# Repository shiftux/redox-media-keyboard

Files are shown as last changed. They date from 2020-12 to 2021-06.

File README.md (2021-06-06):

# Redox Media Keyboard

I've made a custom adaptation of the [Redox](https://hackaday.io/project/160610-redox-keyboard) keyboard, accommodating media buttons as well as a volume knob and a scroll wheel.

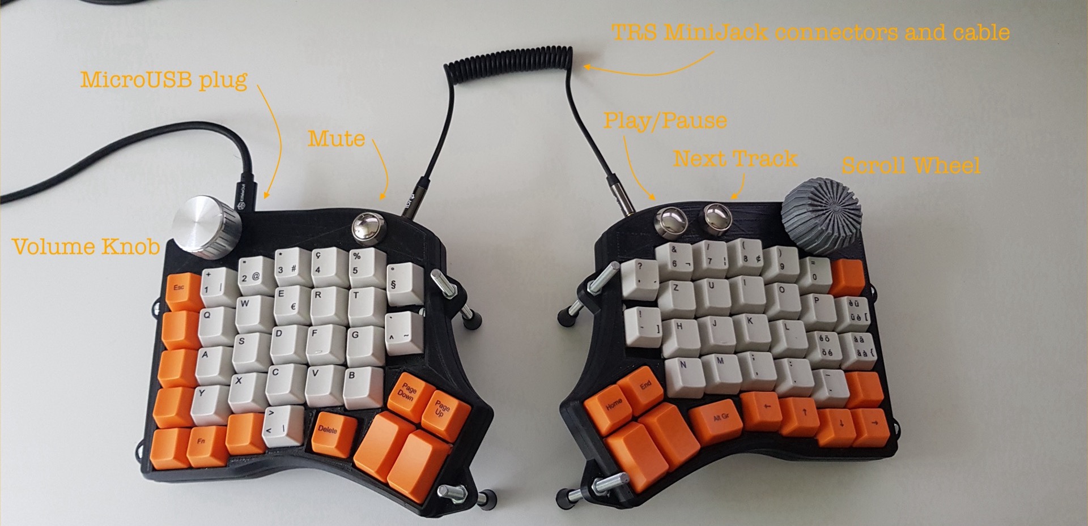
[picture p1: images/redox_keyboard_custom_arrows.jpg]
The Redox Media Keyboard


## Detailed report and video
I've written a [detailed article](https://shiftux.org/making_projects/keyboard.html) and created a [video](https://youtu.be/Cwkf7HFcUkY) video explaining the pros and cons of such a keyboard as well as a build and programming guide.

I recommend reading at least the part about testing of switches and deciding what keyboard you want to go for in the above [article](https://shiftux.org/making_projects/keyboard.html), it will save you from a lot of work later on...

## Wiring diagram
Keyboards are typically wired in a matrix, where every switch is connected to 1 row and 1 column. If the microcontroller detects a connection between a row and a column, it identifies which key is pressed. The [video](https://youtu.be/Cwkf7HFcUkY) explains the wiring in more detail with useful hints of how to prepare the wires.

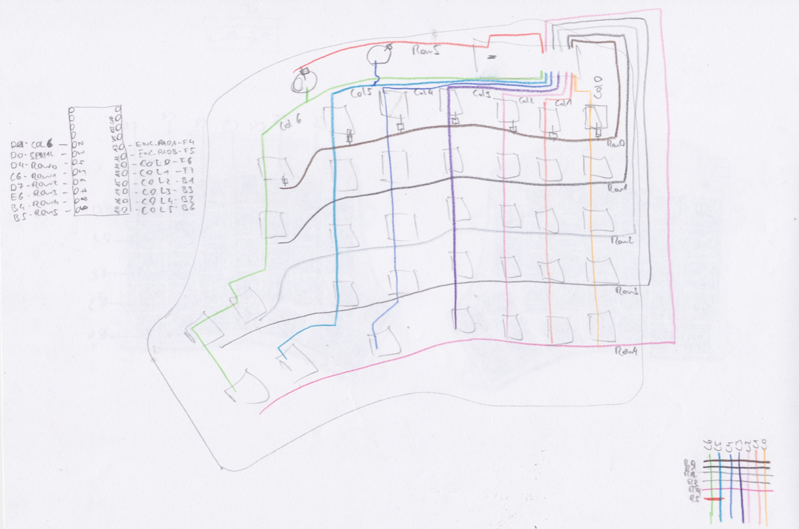
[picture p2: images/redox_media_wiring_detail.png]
The Redox Media Keyboard

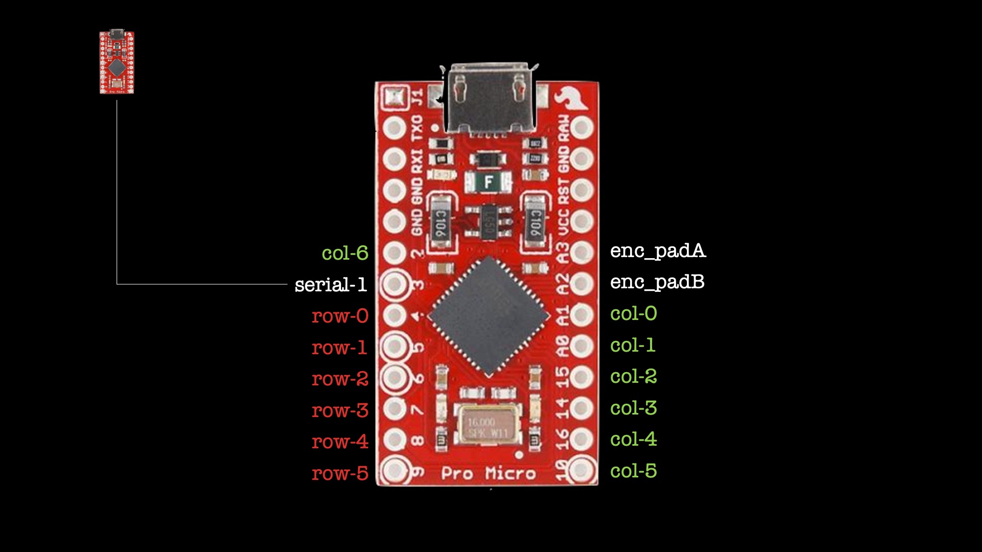
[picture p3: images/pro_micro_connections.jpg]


The wiring diagrams from the Redox community can be found [here](https://hackaday.io/project/160610/logs?sort=oldest)

For easier wiring I recommend first soldering the diodes and then preparing partially de-insulated cables, details can be learned in the [video](https://youtu.be/Cwkf7HFcUkY)  or in [this guide](https://geekhack.org/index.php?topic=87689.0).

## Programming
The keyboard software is based on the QMK framework, as is the original Redox. I've submitted a PR to QMK adding a media layout and corresponding key map. Also instructions to apply and flash the firmware are layed out there, refer to the [Redox Media section in the QMK repo](https://github.com/qmk/qmk_firmware/pull/13084) (currently a PR, but you can check the changes or [my fork](https://github.com/shiftux/qmk_firmware/tree/redox_media/keyboards/redox/media) of the QMK repo in the meantime).

While generating a new layout I highly recommend using the amazing [QMK key tester](https://config.qmk.fm/#/test).

## Bill of material
- [key tester](https://www.amazon.fr/AKWOX-M%C3%A9canique-Interrupteurs-Dampeners-Extracteur/dp/B01GZHU1EG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)
- [sample switches](https://www.pcgamingrace.com/products/glorious-mx-switch-sample-pack)
- [switches (Kailh Pro Purple)](https://www.digitec.ch/de/s1/product/glorious-pc-gaming-race-kailh-pro-purple-switches-120-stueck-maus-tastatur-zubehoer-12826227)
- [Sparkfun pro micro 5V](https://www.play-zone.ch/de/sparkfun-arduino-pro-micro-5v-16mhz.html) 2x
- [curled 3.5mm cable](https://www.brack.ch/hama-audio-kabel-klinke-3-182926)
- [rotary encoder](https://www.digitec.ch/de/s1/product/velleman-digital-rotary-encoder-modul-entwicklungsboard-kit-12256627) 2x
- [shape cable](https://www.fust.ch/de/p/pc-tablet-handy/pc-komponenten/kabel-adapter/delock/usb-otg-kabel-microb-shapecable-0-15-m-8289927.html)
- [1N4148-200mA diodes (as many as you intend to use switches)](https://www.amazon.fr/dp/B07CTW5L3W/ref=pe_3044141_185740131_TE_item)
- [media buttons](https://www.aliexpress.com/item/32908474287.html) 3x
- [micro USB cable](https://www.amazon.fr/dp/B07Q5NQFL1/ref=pe_3044141_185740131_TE_item)
- volume knob
- scroll wheel (printed)
- 5mm threaded rod with nuts
- hook up wire (ideally multiple colors)
- key caps. You can use any old MX type key caps from an old keyboard or order a set of custom ones. I got mine from [here](https://www.maxkeyboard.com/iso-layout-custom-color-cherry-mx-keycap-set-top-print-blank.html), another alternative would be [this](https://candykeys.com/).

## CAD files
The original Redox CAD files (SCAD) are open source and available [here](https://github.com/Lenbok/scad-keyboard-cases). I've modified those adding some extra space at the top to accommodate the media buttons and two knobs. Also, I changed the bottom part of the keyboard so that it has a custom micro-USB slot which perfectly fits the shape cable holding it in place and exposing one end as port socket for the computer-to-keyboard USB cable, that's where the [shape cable](https://www.fust.ch/de/p/pc-tablet-handy/pc-komponenten/kabel-adapter/delock/usb-otg-kabel-microb-shapecable-0-15-m-8289927.html) comes in.

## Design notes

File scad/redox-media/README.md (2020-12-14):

## Redox Keyboard with media buttons and scroll wheel

I wanted to design a new case for the Redox that was inspired both
by the Redox Rev1 case and the Iris, and I thought it would be nice to
start with the layout from the [Keyboard Layout
Editor](http://www.keyboard-layout-editor.com/) JSON file (in this way
it could be extended to other keyboards). Existing tools I had found for
going from KLE JSON to OpenSCAD didn't work for split keyboards where
some keys are rotated, so an updated tool is provided here that seems to
work on the split keyboards I have tried.

redox-top

redox-exploded

redox-completed

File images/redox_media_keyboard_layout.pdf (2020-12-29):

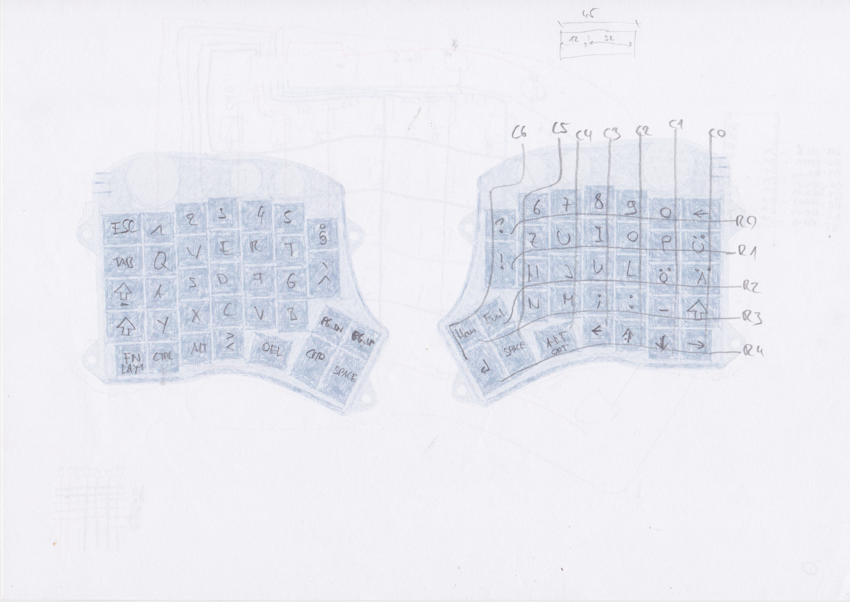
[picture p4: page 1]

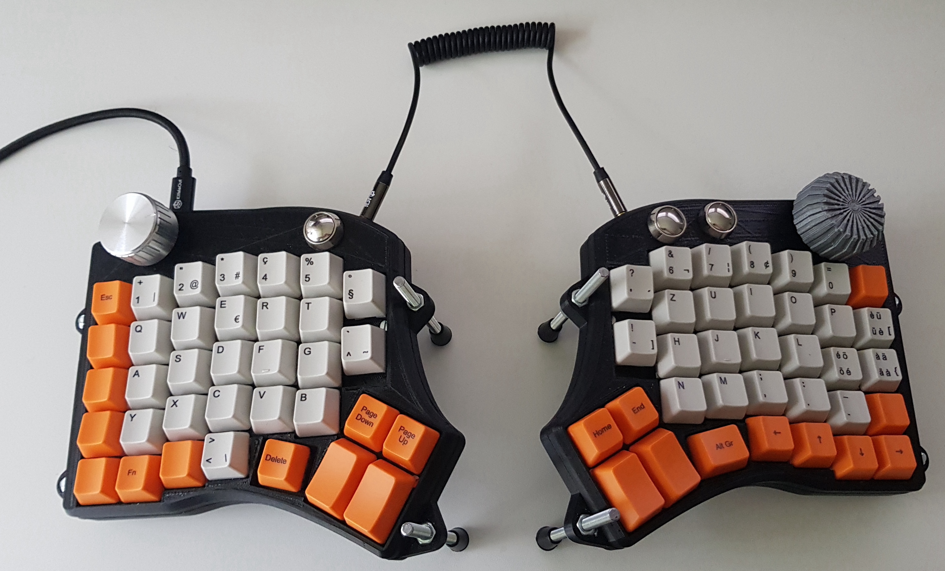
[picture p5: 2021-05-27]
images/the_keyboard.jpg

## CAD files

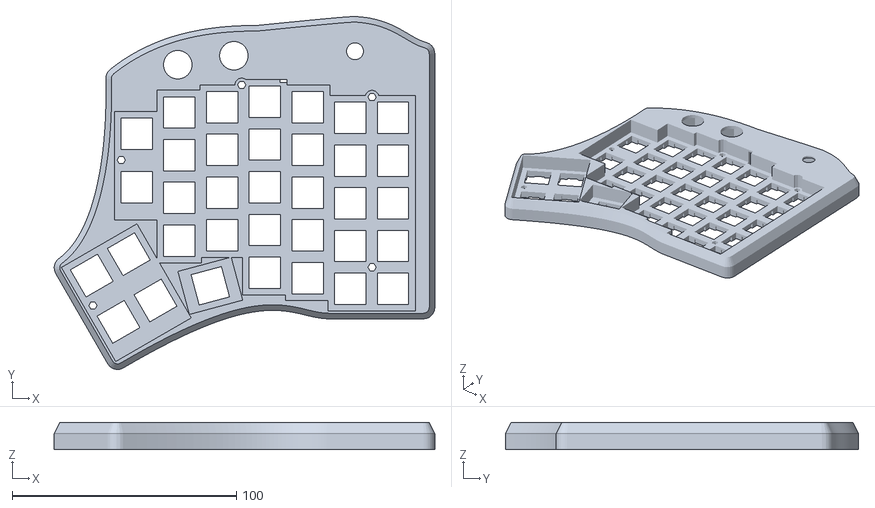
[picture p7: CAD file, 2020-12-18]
CAD/redox-case_top_right.stl
169.7 x 157.4 x 12.2

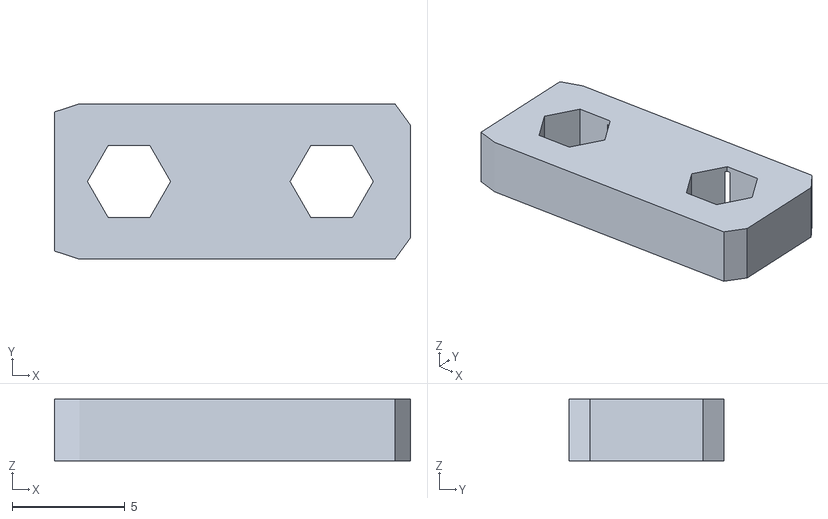
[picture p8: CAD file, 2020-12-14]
scad/misc/stls/Micro_USB_Spacer.stl
15.8 x 6.90 x 2.75

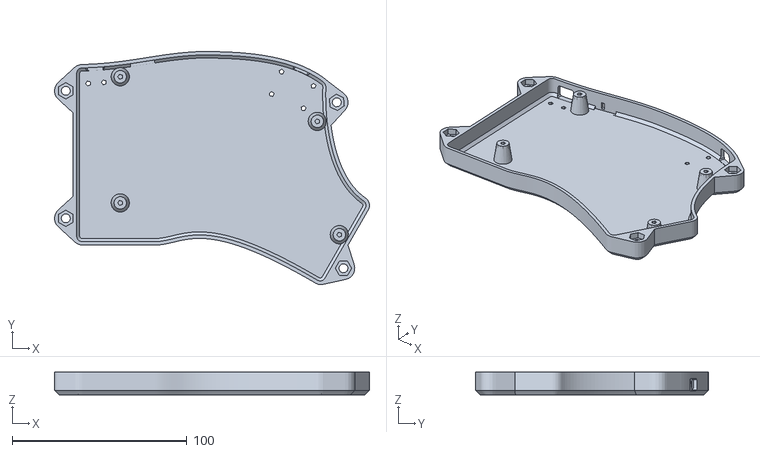
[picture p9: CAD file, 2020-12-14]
scad/redox-media/stls/redox-rev0b-bottom.stl
180.3 x 133.4 x 13.0

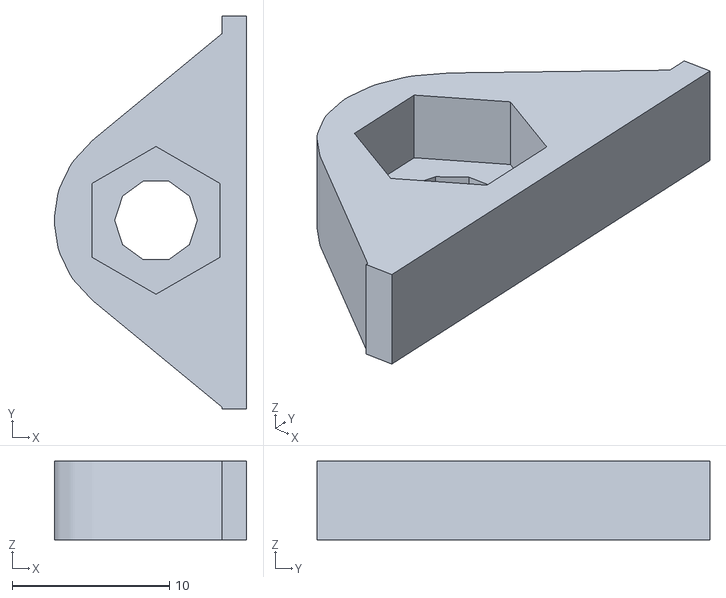
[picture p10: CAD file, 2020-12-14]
scad/stl/redox-case_test.stl
12.2 x 25.0 x 5.00

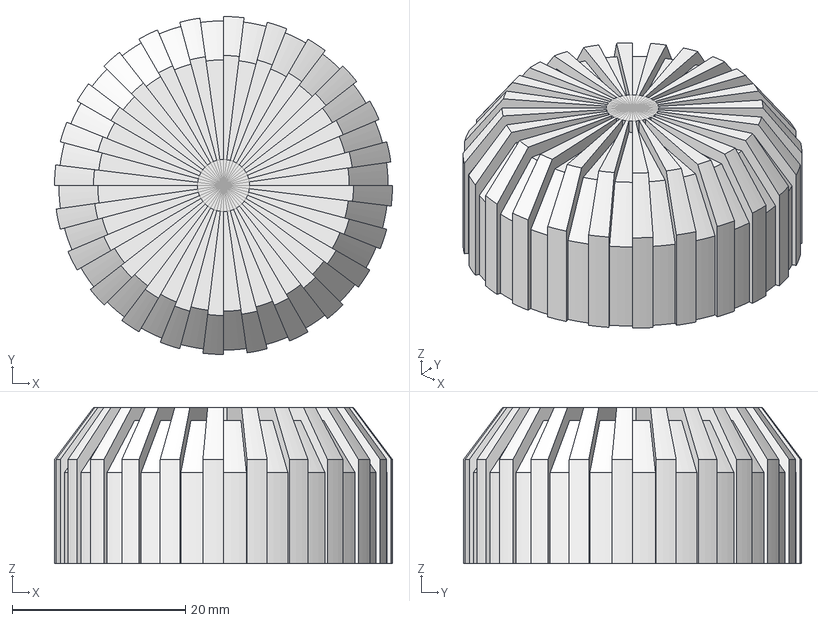
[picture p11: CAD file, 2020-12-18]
CAD/mouse_knob.FCStd
39.0 x 39.0 x 18.0 mm

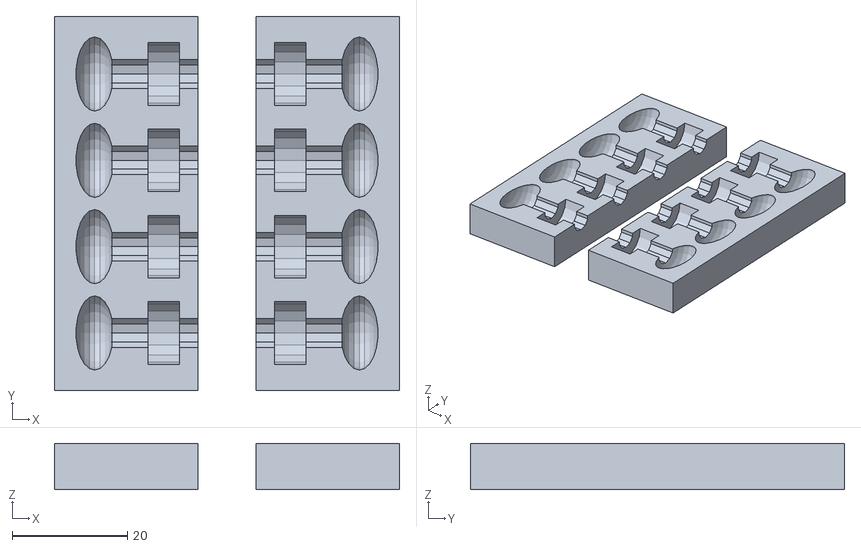
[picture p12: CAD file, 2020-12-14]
scad/misc/stls/Foot_Mold.stl
60.0 x 65.0 x 8.00

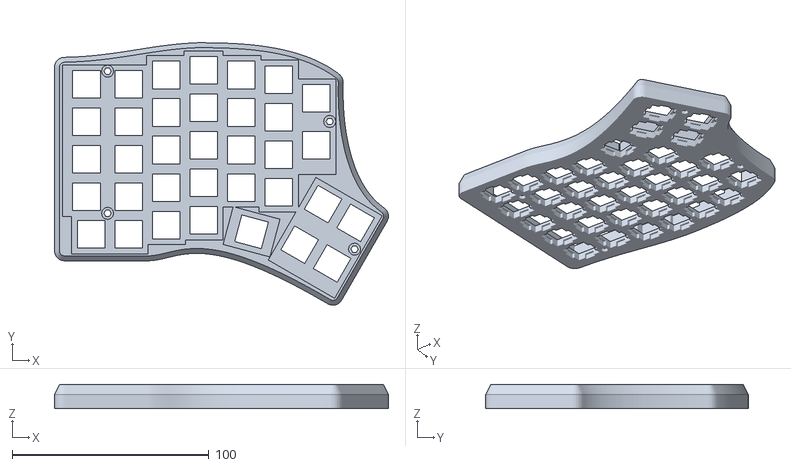
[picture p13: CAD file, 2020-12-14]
scad/redox-media/stls/redox-rev0b-hightop.stl
169.6 x 133.4 x 12.2

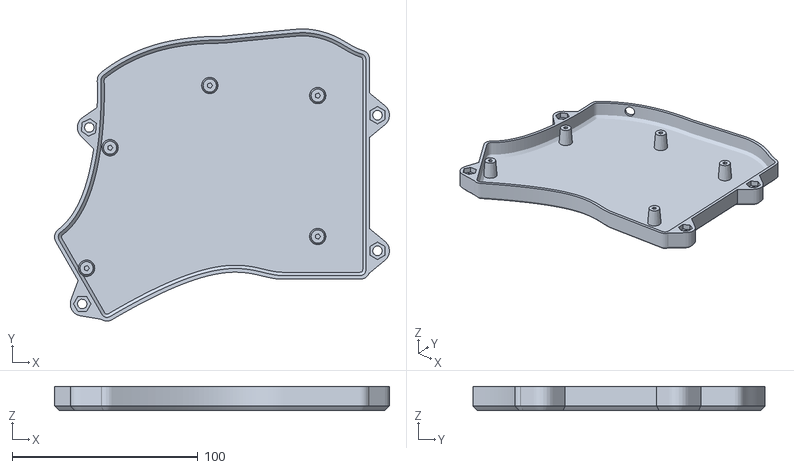
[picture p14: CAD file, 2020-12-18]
CAD/redox-case_bottom_right.stl
180.3 x 157.4 x 13.0

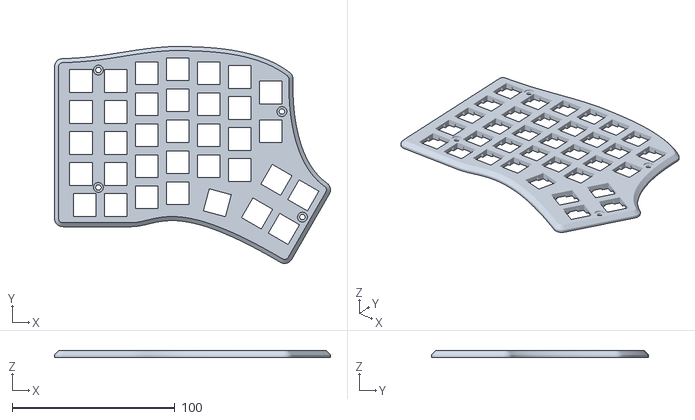
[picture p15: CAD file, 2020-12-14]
scad/redox-media/stls/redox-rev0b-lowtop.stl
169.6 x 133.4 x 4.00

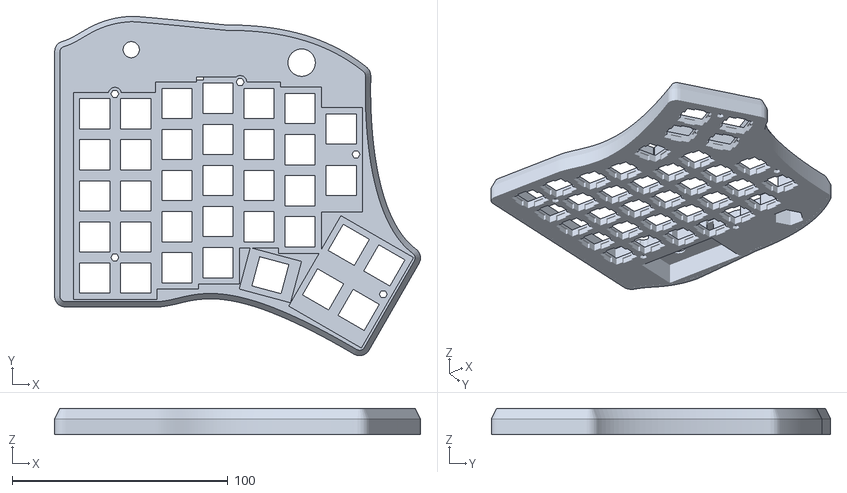
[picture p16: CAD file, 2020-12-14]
CAD/redox-case_top_left.stl
169.7 x 157.4 x 12.2

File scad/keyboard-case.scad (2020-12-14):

unit = 19.05;            // Unit size of spacing between keys

cherry_plate_width = 14; // Width of hole in plate for key insertion. Adjust if needed

plate_thickness = 4;   // Fairly thick for strength, ideally print this section with high infill
top_case_raised_height = 7.2 + 1; // Distance between plate and bottom of keycap plus a little extra, for raised top case
bottom_case_height = 13;  // Enough room to house electonics
wall_thickness = 2;     // Sides and bottom of case
depth_offset = 0;       // How much of side wall to include below top plate

// Case screw sizes
standoff_rad = 7 / 2;
screw_rad = 3.2 / 2;
screw_head_rad = 6 / 2;
screw_length = 8;
bottom_screws = false; // Default is to screw down from the top

themes = [
    //    case,    keycap, keyswitch,  keystem
    ["#101010", "#130044", "#222222", "#aa3333"],
    ["#180054", "#73d373", "#222222", "#aa3333"],
    ["#bbbbff", "#73d373", "#222222", "#aa3333"],
    ["#9999bb", "#252525", "#cccccc", "#553333"],
    ];
theme = 3;
case_color = themes[theme].x;
keycap_color = themes[theme].y;
keyswitch_color = themes[theme].z;
keystem_color = themes[theme][3];

// Create a hole where a switch can be inserted. The top of the hole is at 0
cherry_clip_recess_z = 1.3; // How far below the top the recess begins
cherry_clip_recess_width = 6; // How much of the side is taken up by the recess
cherry_clip_recess_depth = 1.0; // How far in does the clip go
cherry_clip_recess_height = 4.0; // How far down clip recess go
module switch_hole(size, depth = 5) {
    translate([0, 0, -depth]) {
        linear_extrude(height = depth + 0.01, center = false, convexity = 3)
            square([cherry_plate_width, cherry_plate_width], center = true);
        translate([0, 0, depth - cherry_clip_recess_z - cherry_clip_recess_height]) linear_extrude(height = cherry_clip_recess_height, center = false, convexity = 3)
            for (r = [0, 90])
                rotate([0, 0, r])
                    square([cherry_plate_width + 2 * cherry_clip_recess_depth, cherry_clip_recess_width], center = true);
    }
}

// A keyswitch for preview purposes
cherry_switch_width = 14;
cherry_switch_depth = 5.2;
module cherry_keyswitch() {
    color(keystem_color) translate([0, 0, 5]) {
        translate([0, 0, 0.5]) cube([7, 5.7, 1], center = true);
        translate([0, 0, 1 + 1.8])
            for (r = [0, 90])
                rotate([0, 0, r])
                cube([4.0, 1.2, 3.6], center = true);
    }
    color(keyswitch_color) {
        hull() {
            translate([0, 0, 0.99]) linear_extrude(height = 0.01, center = false, convexity = 3)
                square([14, 14], center = true);
            translate([0, 0, 5.6]) linear_extrude(height = 0.01, center = false, convexity = 3)
                square([11, 11], center = true);
        }
        translate([0, 0, 0.5]) cube([15.6, 15.6, 1], center = true);
        translate([0, 0, -8.3]) cylinder(r = 3.8 / 2, h = 5, $fn = 8);
        hull() {
            linear_extrude(height = 0.01, center = false, convexity = 3)
                square([cherry_switch_width, cherry_switch_width], center = true);
            translate([0, 0, -cherry_switch_depth]) linear_extrude(height = 0.01, center = false, convexity = 3)
                square([cherry_switch_width-0.5, cherry_switch_width-0.5], center = true);
        }
    }
}

// Something roughly DSA-ish for preview purposes
keycap_depth_offset = 7.2;  // Distance from bottom of keycap to top of plate.
module simple_keycap(size) {
    color(keycap_color) translate([0, 0, keycap_depth_offset]) hull() {
        linear_extrude(height = 0.01, center = false, convexity = 3)
            offset(delta = -0.4, chamfer = false) square(size * unit, center = true);
        translate([0, 0, 8]) linear_extrude(height = 0.01, center = false, convexity = 3)
            offset(r = 2, $fn = 16) offset(delta = -5.5) square(size * unit, center = true);
    }
}

// Negative space for a keycap for raised top cases
module keycap_hole(size, depth = top_case_raised_height) {
    linear_extrude(height = depth + 1, center = false, convexity = 3)
        offset(delta = 0.4) square(size * unit, center = true);
}

// Negative space for a key switch plus keycap
module case_switch_hole(size) {
    keycap_hole(size);
    switch_hole(size);
}

// For subtracting a hole in the bottom case for a microswitch
module reset_microswitch(hole = true) {
    color("#202020") cube([14, 6, 6], center = false);
    color("red") translate([4, 0.01, 1])  cube([2, hole ? 10 : 7, 4], center = false);
}

// Typical mini USB breakout boards from e.g. Aliexpress
mini_usb_screw_dia = 3.0;
mini_usb_screw_rad = (mini_usb_screw_dia - 0.6) / 2; // Smaller than M3 to tap into
mini_usb_screw_sep = 20;
mini_usb_hole_height = 7.5;
module mini_usb_hole(hole = true) {
    color("green") translate([0, -11, pcb_thickness/2]) cube([25.5, 19.5, pcb_thickness], center = true);
    if (hole) {
        translate([0, 0, mini_usb_hole_height/2])  rotate([90, 0, 0]) roundedcube([10, mini_usb_hole_height, 10], r=1.5, center=true, $fs=1);
    }
    color("silver") translate([0, -5, mini_usb_hole_height/2])  rotate([90, 0, 0]) cube([7.6, 3.7, 9.2], center=true, $fs=1);
    for (i = [-1,1], j = [0, 14]) {
        translate([i*mini_usb_screw_sep/2, -4-j, -5]) polyhole(r=mini_usb_screw_rad, h=10);
    }
}

// Typical micro USB breakout boards from e.g. Aliexpress
micro_usb_screw_dia = 3.0;
micro_usb_screw_rad = (micro_usb_screw_dia - 0.6) / 2; // Smaller than M3 to tap into
micro_usb_screw_sep = 9;
micro_usb_hole_width = 11;
micro_usb_hole_height = 7.5;
micro_usb_socket_height = 2.5;
pcb_thickness = 2;
module micro_usb_hole(hole = true) {
    color("green") translate([0, -8, pcb_thickness/2]) cube([14, 14, pcb_thickness], center = true);
    color("silver") {
        if (hole) {
            translate([0, 1, pcb_thickness+micro_usb_socket_height/2]) rotate([90, 0, 0]) roundedcube([micro_usb_hole_width, micro_usb_hole_height, 10], r=1.5, center=true, $fs=1);
        }
        translate([0, -3, pcb_thickness + micro_usb_socket_height / 2]) rotate([90, 0, 0]) cube([7.5, micro_usb_socket_height, 7], center = true, $fs = 1);
    }
    for (i = [-1,1]) {
        translate([i * micro_usb_screw_sep/2, -8, -5]) polyhole(r = micro_usb_screw_rad, h = 15);
    }
}

// You can use this for things that don't need to vary each child according to the key (e.g. size)
module key_positions(keys) {
    // Mirror because KLE has Y axis reversed
    mirror([0, 1, 0]) for (key = keys)
        position_key(key, unit = unit)
            children();
}

module key_holes(keys, type = "both") {
    //echo("Number of keys:",len(keys));
    // Mirror because KLE has Y axis reversed
    mirror([0, 1, 0]) for (key = keys) {
        position_key(key, unit = unit)
            if (type == "both") {
                case_switch_hole(key_size(key));
            } else if (type == "plate") {
                switch_hole(key_size(key));
            } else if (type == "switch") {
                cherry_keyswitch();
            } else if (type == "keycap") {
                simple_keycap(key_size(key));
            }
    }
}

module screw_positions(screws) {
    for (screw = screws) translate(screw) children();
}

module screw_holes(screws, screw_depth = 8, screw_head_depth = plate_thickness + top_case_raised_height) {
    screw_positions(screws) {
        mirror([0, 0, 1]) translate([0, 0, -screw_head_depth]) bolthole(r1=screw_head_rad, r2=screw_rad, h1=screw_head_depth, h2=screw_depth);
    }
}


// M5 bolt tenting
tent_bolt_rad = 5 / 2;
tent_nut_rad = 9.4 / 2;
tent_nut_height = 3.5;
tent_attachment_width = 35;
module tent_support(position, angle, height = bottom_case_height, lift = 0) {
    base_chamfer = 2.5;
    off = apothem(tent_nut_rad, 6) + 0.5;
    translate([position.x, position.y, lift]) rotate([0, 0, angle]) {
        difference() {
            chamfer_extrude(height = height, chamfer = base_chamfer, faces = [true, false]) {
                hull() {
                    translate([-6.5, 0]) square([0.1, tent_attachment_width], center = true);
                    translate([off, 0]) circle(r = tent_bolt_rad + base_chamfer + 1.5);
                }
            }
            //translate([-10,-20, -0.1]) cube([10-base_chamfer, 40, bottom_case_height+1], center=false);
            // Screw hole
            translate([off, 0, -0.1]) polyhole(r=tent_bolt_rad, h=height+1);
            // Nut hole
            translate([off, 0, height-tent_nut_height]) rotate([0, 0, 60/2]) cylinder(r=tent_nut_rad, h=tent_nut_height+0.1, $fn=6);
        }
    }
}
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

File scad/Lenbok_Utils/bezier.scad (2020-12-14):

// Downloaded from https://www.thingiverse.com/thing:2207518
/* 
Copyright (c) 2017 Alexander R. Pruss.

Licensed under any Creative Commons Attribution license you like or under the 
following MIT License.

Permission is hereby granted, free of charge, to any person obtaining a copy
of this software and associated documentation files (the "Software"), to deal
in the Software without restriction, including without limitation the rights
to use, copy, modify, merge, publish, distribute, sublicense, and/or sell
copies of the Software, and to permit persons to whom the Software is
furnished to do so, subject to the following conditions:

The above copyright notice and this permission notice shall be included in all
copies or substantial portions of the Software.

THE SOFTWARE IS PROVIDED "AS IS", WITHOUT WARRANTY OF ANY KIND, EXPRESS OR
IMPLIED, INCLUDING BUT NOT LIMITED TO THE WARRANTIES OF MERCHANTABILITY,
FITNESS FOR A PARTICULAR PURPOSE AND NONINFRINGEMENT. IN NO EVENT SHALL THE
AUTHORS OR COPYRIGHT HOLDERS BE LIABLE FOR ANY CLAIM, DAMAGES OR OTHER
LIABILITY, WHETHER IN AN ACTION OF CONTRACT, TORT OR OTHERWISE, ARISING FROM,
OUT OF OR IN CONNECTION WITH THE SOFTWARE OR THE USE OR OTHER DEALINGS IN THE
SOFTWARE. 

*/


// Public domain Bezier stuff from www.thingiverse.com/thing:8443
function BEZ03(u) = pow((1-u), 3);
function BEZ13(u) = 3*u*(pow((1-u),2));
function BEZ23(u) = 3*(pow(u,2))*(1-u);
function BEZ33(u) = pow(u,3);
function PointAlongBez4(p0, p1, p2, p3, u) = [for (i=[0:len(p0)-1]) 
	BEZ03(u)*p0[i]+BEZ13(u)*p1[i]+BEZ23(u)*p2[i]+BEZ33(u)*p3[i]];
// End public domain Bezier stuff

function REPEAT_MIRRORED(v) = ["m",v];
function SMOOTH_REL(x) = ["r",x];
function SMOOTH_ABS(x) = ["a",x];
function SYMMETRIC() = ["r",1];
function OFFSET(v) = ["o",v];
function SHARP() = OFFSET([0,0,0]);
function POLAR(r,angle) = OFFSET(r*[cos(angle),sin(angle)]);
function POINT_IS_SPECIAL(v) = (v[0]=="r" || v[0]=="a" || v[0]=="o");

// this does NOT handle offset type points; to handle those, use DecodeBezierOffsets()
function getControlPoint(cp,node,otherCP) = cp[0]=="r"?(node+cp[1]*(node-otherCP)):( cp[0]=="a"?node+cp[1]*(node-otherCP)/norm(node-otherCP):cp );

function onLine2(a,b,c,eps=1e-4) =
    norm(c-a) <= eps ? true 
        : norm(b-a) <= eps ? false /* to be safe */
            : abs((c[1]-a[1])*(b[0]-a[0]) - (b[1]-a[1])*(c[0]-a[0])) <= eps * eps && norm(c-a) <= eps + norm(b-a);

function isStraight2(p1,c1,c2,p2,eps=1e-4) = 
    len(p1) == 2 &&
    onLine2(p1,p2,c1,eps=eps) && onLine2(p2,p1,c2,eps=eps);

function Bezier2(p,index=0,precision=0.05,rightEndPoint=true) = let(nPoints=ceil(1/precision)) 
    isStraight2(p[index],p[index+1],p[index+2],p[index+3]) ? (rightEndPoint?[p[index+0],p[index+3]]:[p[index+0]] ) :
    [for (i=[0:nPoints-(rightEndPoint?0:1)]) PointAlongBez4(p[index+0],p[index+1],p[index+2],p[index+3],i/nPoints)];
    
function flatten(listOfLists) = [ for(list = listOfLists) for(item = list) item ];


// p is a list of points, in the format:
// [node1,control1,control2,node2,control3, control4,node3, ...]
// You can replace inner control points with:
//   SYMMETRIC: uses a reflection of the control point on the other side of the node
//   SMOOTH_REL(x): like SYMMETRIC, but the distance of the control point to the node is x times the distance of the other control point to the node
//   SMOOTH_ABS(x): like SYMMETRIC, but the distance of the control point to the node is exactly x
// You can also replace any control point with:
//   OFFSET(v): puts the control point at the corresponding node plus the vector v
//   SHARP(): equivalent to OFFSET([0,0]); useful for straight lines
//   POLAR(r,angle): like OFFSET, except the offset is specified in polar coordinates

function DecodeBezierOffset(control,node) = control[0] == "o" ? node+control[1] : control;

function _mirrorMatrix(normalVector) = let(v = normalVector/norm(normalVector)) len(v)<3 ? [[1-2*v[0]*v[0],-2*v[0]*v[1]],[-2*v[0]*v[1],1-2*v[1]*v[1]]] : [[1-2*v[0]*v[0],-2*v[0]*v[1],-2*v[0]*v[2]],[-2*v[0]*v[1],1-2*v[1]*v[1],-2*v[1]*v[2]],[-2*v[0]*v[2],-2*v[1]*v[2],1-2*v[2]*v[2]]];

function _correctLength(p,start=0) = 
    start >= len(p) || p[start][0] == "m" ? 3*floor(start/3)+1 : _correctLength(p,start=start+1);

function _trimArray(a, n) = [for (i=[0:n-1]) a[i]];

function _transformPoint(matrix,a) = 
    let(n=len(a))
        len(matrix[0])==n+1 ? 
            _trimArray(matrix * concat(a,[1]), n)
            : matrix * a;

function _transformPath(matrix,path) =
    [for (a=path) _transformPoint(matrix,a)];

function _reverseArray(array) = let(n=len(array)) [for (i=[0:n-1]) array[n-1-i]];

function _stitchPaths(a,b) = let(na=len(a)) [for (i=[0:na+len(b)-2]) i<na? a[i] : b[i-na+1]-b[0]+a[na-1]];

// replace all OFFSET/SHARP/POLAR points with coordinates
function DecodeBezierOffsets(p) = [for (i=[0:_correctLength(p)-1]) i%3==0?p[i]:(i%3==1?DecodeBezierOffset(p[i],p[i-1]):DecodeBezierOffset(p[i],p[i+1]))];
    
function _mirrorPaths(basePath, control, start) =
    control[start][0] == "m" ? _mirrorPaths(_stitchPaths(basePath,_reverseArray(_transformPath(_mirrorMatrix( control[start][1] ),basePath))), control, start+1) : basePath;

function DecodeSpecialBezierPoints(p0) = 
    let(
        l = _correctLength(p0),
        doMirror = len(p0)>l && p0[l][0] == "m",
        p=DecodeBezierOffsets(p0),
        basePath = [for (i=[0:l-1]) i%3==0?p[i]:(i%3==1?getControlPoint(p[i],p[i-1],p[i-2]):getControlPoint(p[i],p[i+1],p[i+2]))])
        doMirror ? _mirrorPaths(basePath, p0, l) : basePath;

function Distance2D(a,b) = sqrt((a[0]-b[0])*(a[0]-b[0])+(a[1]-b[1])*(a[1]-b[1]));

function RemoveDuplicates(p,eps=0.00001) = let(safeEps = eps/len(p)) [for (i=[0:len(p)-1]) if(i==0 || i==len(p)-1 || Distance2D(p[i-1],p[i]) >= safeEps) p[i]];

function Bezier(p,precision=0.05,eps=0.00001) = let(q=DecodeSpecialBezierPoints(p), nodes=(len(q)-1)/3) RemoveDuplicates(flatten([for (i=[0:nodes-1]) Bezier2(q,index=i*3,precision=precision,rightEndPoint=(i==nodes-1))]),eps=eps);
    
module BezierVisualize(p,precision=0.05,eps=0.00001,lineThickness=0.25,controlLineThickness=0.125,nodeSize=1) {
    $fn = 16;
    dim = len(p[0]);
    module point(size) {
        if (dim==2)
            circle(d=size);
        else
            sphere(d=size);
    }
    p1 = DecodeSpecialBezierPoints(p);
    l = Bezier(p1,precision=precision,eps=eps);
    for (i=[0:len(l)-2]) {
        hull() {
            translate(l[i]) point(lineThickness);
            translate(l[i+1]) point(lineThickness);
        }
    }
    for (i=[0:len(p1)-1]) {
        if (i%3 == 0) {
            color("black") translate(p1[i]) point(nodeSize);
        }
        else {
            node = i%3 == 1 ? i-1 : i+1;
            color("red") translate(p1[i]) point(nodeSize);
            color("red") hull() {
                translate(p1[node]) point(controlLineThickness);
                translate(p1[i]) point(controlLineThickness);
            }
        }
    }
}

//<skip>

module _ribbon(thickness=2) {
    for (i=[1:len(p)-1]) {
                hull() {
                    translate(p[i-1]) 
                        sphere(thickness/2);
                    translate(p[i]) 
                        sphere(thickness/2);
                }
            }
}

translate([-20,0,0])
BezierVisualize([[0,0,10],[10,5,3],[10,10,20],[20,20,20],SYMMETRIC(),[0,0,8],[0,0,0]], lineThickness=1,nodeSize=2);

translate([0,-15]) BezierVisualize([[0,0],/*C*/[5,0],/*C*/OFFSET([-5,0]),[10,10],REPEAT_MIRRORED([1,0]),REPEAT_MIRRORED([0,1]) ]);
linear_extrude(height=5) {
polygon(Bezier([[0,0],/*C*/[5,0],/*C*/SYMMETRIC(),[10,10],/*C*/[15,10],/*C*/OFFSET([-5,0]),[20,0]],precision=0.05));
translate([0,15])
polygon(Bezier([[0,0],/*C*/[5,0],/*C*/SMOOTH_REL(2),[10,10],/*C*/[15,10],/*C*/POLAR(5,180),[20,0]],precision=0.05));
translate([0,30])
polygon(Bezier([[0,0],/*C*/[5,0],/*C*/SMOOTH_ABS(1.5),[10,10],/*C*/[15,10],/*C*/OFFSET([-5,0]),[20,0]],precision=0.05));
translate([0,45])
polygon(Bezier([[0,0],/*C*/[5,0],/*C*/SMOOTH_REL(-1),[10,10],/*C*/[15,10],/*C*/OFFSET([-5,0]),[20,0]],precision=0.05));
translate([0,60])
polygon(Bezier([[0,0],/*C*/[5,0],/*C*/SMOOTH_ABS(-1),[10,10],/*C*/[15,10],/*C*/OFFSET([-5,0]),[20,0]],precision=0.05));
translate([0,75])
polygon(Bezier([[0,0],/*C*/SHARP(),/*C*/SHARP(),[10,10],/*C*/SHARP(),/*C*/OFFSET([-5,0]),[20,0]],precision=0.05));
}
//</skip>

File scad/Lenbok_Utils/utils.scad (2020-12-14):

// My utility functions

// Put it in your openscad library path and use with:
// use<Lenbok_Utils/utils.scad>

// Example improved resolution control
//$fa=1;
//$fs=5; // Use for fast rendering
//$fs=1; // Uncomment for export

fudge = 0.02;

// Some default screw characteristics - for M3 screws
defScrewRad = 3.5/2;
defScrewDepth = 5;
defScrewHeadRad = 6/2;
defScrewHeadDepth = 3.5;

defLayer = 0.25; // default layer thickness
tolerance = 0.5;

/** Calculates length of hypotenuse according to pythagoras theorum */
function pythag(x, y) = sqrt(x * x + y * y);

/** Converts a vector to unit length */
function unit_vector(v) = v / norm(v);

/** Length of apothem given radius and number of sides */
function apothem(r, n = 6) = r * cos(180/n);

/** Length of radius given apothem and number of sides */
function inv_apothem(a, n = 6) = a / cos(180/n);

/** From the OpenSCAD wiki. */
function sublist(list, from=0, to) =
    from > to
    ? []
    : let(end = to==undef ? len(list) - 1 : to)
        [for(i = [from : end]) list[i]];

/** From the OpenSCAD wiki. */
module fillet(r = 1) {
    offset(r = -r) offset(delta = r) children();
}

/** From the OpenSCAD wiki. */
module round(r = 1) {
    offset(r = r) offset(delta = -r) children();
}

// Copyright 2011 Nophead (of RepRap fame)
// Using this holes should come out approximately right when printed
module polyhole2d(r) {
    n = max(round(4 * r), 3);
    rotate([0, 0, 180]) circle(r = r / cos (180 / n), $fn = n);
}
module polyhole(r, h, center = false) {
    translate(center ? [0, 0, -h / 2] : [0, 0, 0]) linear_extrude(height = h) polyhole2d(r);
}

module test_polyhole(){
    difference() {
	cube(size = [100, 27, 3]);
        union() {
    	    for(i = [1:10]) {
                translate([(i * i + i) / 2 + 3 * i, 8, -1])
                polyhole(h = 5, r = i / 2);
                
                assign(d = i + 0.5)
                translate([(d * d + d) / 2 + 3 * d, 19, -1])
                polyhole(h = 5, r = d / 2);
    	    }
        }
    }
}

/**
 * Reorients children with respect to the given vector
 * @param v the vector
 * @param a the assumed current origin vector (default Z axis)
 */
module orient(v, a = [0, 0, 1], roll = 0) {
    angle = acos((a * v) / (norm(a) *norm(v)));
    rotate(a = angle, v = cross(a, v))
        rotate([0, 0, roll])
        children();
}

/**
 * Projection from 3d children to 2d along a plane defined by a vector
 * @param v the vector
 */
module projection_plane(v, roll = 0) {
    projection(cut = true) orient(v, roll = roll) translate(-v) children();
}

/**
 * Perform a difference between the children and the plane
 * defined by the supplied vector.
 * @param v the vector
 * @param near if true, keep the side closest to the origin, if false, keep the side away from the origin
 */
module difference_plane(v, near = true) {
    huge = 10000; // Too large gives preview artifacts
    offset = near ? huge / 2 : -huge / 2;
    translate(v) orient(v, roll = 180) difference() {
        orient(v, roll = 180) translate(-v) children();
        translate([0, 0, offset]) cube([huge, huge, huge], center = true);
    }
}

/**
 * Produce a slice defined by the projection along a plane, expanded to the specified width.
 * @param v the vector defining the plane
 * @param thickness the thickness of the slice to create
 */
module slice(v, thickness = 2) {
    translate(v) orient(v, roll = 180) difference() {
        translate([0, 0, -thickness / 2]) linear_extrude(height = thickness) projection_plane(v, roll = 180) children();
    }
}

/**
 * Remove a slice of an object along a plane.
 * @param v the vector defining the plane
 * @param thickness the thickness of the slice to remove
 * @param rejoin if true, re-join the parts
 */
module remove_slice(v, thickness = 2, rejoin = false) {
    fudge = 0.01; // allow some overlap to avoid coincident faces
    shift = rejoin ? unit_vector(v) * (thickness / 2 + fudge) : 0;
    v1 = v - unit_vector(v) * thickness / 2;
    v2 = v + unit_vector(v) * thickness / 2;
    s2 = v * v2 >= 0 ? 1 : -1;
    translate(shift) difference_plane(v1, near = v * v1 >= 0) children();
    translate(-shift) difference_plane(v2 * s2, near = v * v2 <= 0) children();
}

/**
 * insert a slice of an object along a plane and re-join the parts.
 * @param v the vector defining the plane
 * @param thickness the thickness of the slice to remove
 */
module insert_slice(v, thickness = 2) {
    fudge = 0.01; // allow some overlap to avoid coincident faces
    shift = unit_vector(v) * (thickness / 2 - fudge);
    translate(-shift) difference_plane(v, near = true) children();
    slice(v, thickness = thickness) children();
    translate(shift) difference_plane(v, near = false) children();
}

/**
 * Example: centerxy(cubesize) cube(cubesize, center = false);
 */
module centerxy(size = [0, 0]) {
    translate([-size[0] / 2, -size[1] / 2, 0]) children();
}

/**
 * Make an oval
 * @param rWidth the radius of the width
 * @param rHeight the radius of the height
 */
module oval(rWidth = 20, rHeight = 10) {
    scale([1, rHeight / rWidth, 1]) circle(r = rWidth);
}


/** 
 * Displays the current build volume of my original mendel
 */
module mendelBuildVolume() {
    %translate([-90, -80, 0]) cube([90+101,160,55]);
    %translate([-73, -80, 0]) cube([73+93,160,125]);
}

/**
 * Take the convex hull of successive pairs of children
 * @children shapes to successively connect
 */
module hullchain() {
    for (i = [0:$children - 2]) {
        hull() {
            children(i);
            children(i + 1);
        }
    }
}

/**
 * Make an object suitable for creating a hole for a countersink screw.
 * @param r1 head (widest) radius
 * @param r2 screw (narrowest) radius
 * @param h1 depth of head to start of countersink
 * @param h2 depth of screw from start of countersink to end (i.e. total length = h1+h2)
 */
module countersink(r1=defScrewHeadRad, r2=defScrewRad, h1=defScrewHeadDepth, h2=defScrewDepth) {
    sinkheight=r1-r2;
    polyhole(r = r1, h = h1 + fudge);
    translate([0, 0, h1]) cylinder(r1 = r1, r2 = r2, h = sinkheight + fudge);
    translate([0, 0, h1 + sinkheight]) polyhole(r = r2, h = h2 - sinkheight);
}
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

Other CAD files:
CAD/redox-case_bottom_left.stl
scad/redox-media/redox-case.scad
CAD/mouse_knob.stl
scad/misc/misc-parts.scad
scad/redox-media/kle/redox-layout.scad

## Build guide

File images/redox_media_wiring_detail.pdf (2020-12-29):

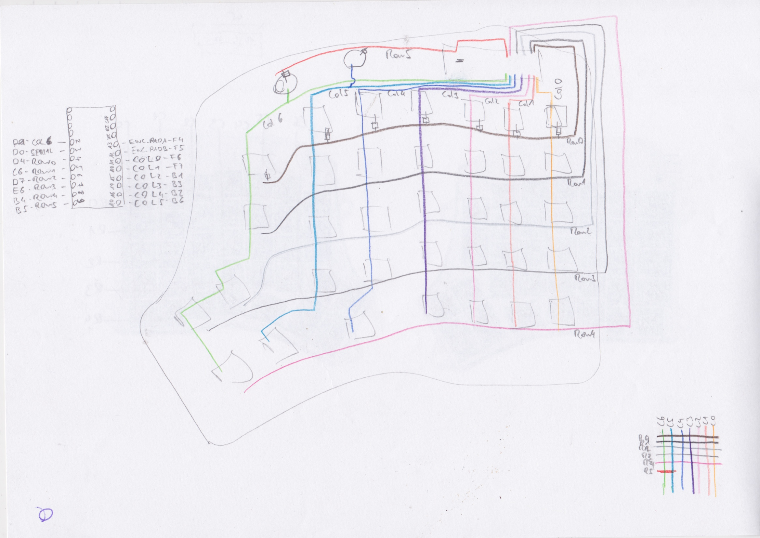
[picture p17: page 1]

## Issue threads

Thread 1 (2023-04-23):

Media buttons size

5721309, 2023-04-23:
Hello. Thanks for sharing this project!

I am going to build your keyboard for myself and trying to buy needed components.
I think the link you have in README is incorrect because there are 16mm media buttons,
but I discovered that hole diameter is actually 12 mm in your scad module.
Am I right that I need 12mm model? Or 16mm model on aliexpress is the correct one?

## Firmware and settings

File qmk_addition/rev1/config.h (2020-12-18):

/*
Copyright 2018 Mattia Dal Ben <matthewdibi@gmail.com>

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
You should have received a copy of the GNU General Public License
along with this program.  If not, see <http://www.gnu.org/licenses/>.
*/

#pragma once

#include "config_common.h"

/* USB Device descriptor parameter */
#define VENDOR_ID       0xFEED
#define PRODUCT_ID      0x0000
#define DEVICE_VER      0x0100
#define MANUFACTURER    shiftux
#define PRODUCT         The Redox Keyboard
#define DESCRIPTION     Split Ergodox-like 5x7 custom keyboard

/* key matrix size */
// Rows are doubled-up
#define MATRIX_ROWS 12
#define MATRIX_COLS 7

// wiring of each half
#define MATRIX_ROW_PINS { D4, C6, D7, E6, B4, B5 }
#define MATRIX_COL_PINS { F6, F7, B1, B3, B2, B6, D1 }
// #define MATRIX_COL_PINS { B6, B2, B3, B1, F7, F6, F5} //uncomment this line and comment line above if you need to reverse left-to-right key order

/* COL2ROW or ROW2COL */
#define DIODE_DIRECTION COL2ROW

/* define if matrix has ghost */
//#define MATRIX_HAS_GHOST

/* number of backlight levels */
// #define BACKLIGHT_LEVELS 3

/* Set 0 if debouncing isn't needed */
#define DEBOUNCE 5

/* serial.c configuration for split keyboard */
#define SOFT_SERIAL_PIN D0

/* Mechanical locking support. Use KC_LCAP, KC_LNUM or KC_LSCR instead in keymap */
#define LOCKING_SUPPORT_ENABLE
/* Locking resynchronize hack */
#define LOCKING_RESYNC_ENABLE

#define ENCODERS_PAD_A { F4 }
#define ENCODERS_PAD_B { F5 }
#define ENCODER_RESOLUTION 4

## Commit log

2020-12-14 SCAD files
    [Foot_Mold.stl, Micro_USB_Spacer.stl, bezier.scad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]
2020-12-14 added stl files
    [redox-case_bottom_left.stl, redox-case_test.stl, redox-case_top_left.stl]
2020-12-18 added cad files
    [mouse_knob.FCStd, mouse_knob.stl, redox-case.scad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]

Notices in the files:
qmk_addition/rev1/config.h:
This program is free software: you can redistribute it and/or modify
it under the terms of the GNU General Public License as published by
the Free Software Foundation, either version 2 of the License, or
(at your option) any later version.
